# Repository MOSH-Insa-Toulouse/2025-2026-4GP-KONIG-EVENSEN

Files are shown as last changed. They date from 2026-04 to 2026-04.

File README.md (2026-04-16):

# LOWTECH FLEX SENSOR
## 2025-2026-4GP-KONIG-EVENSEN

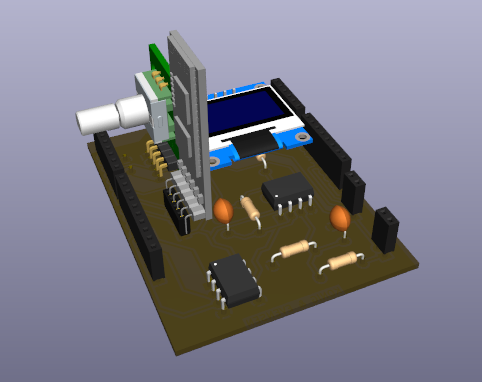
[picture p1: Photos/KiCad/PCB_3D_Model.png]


This work is regulated by the Creative Commons Licence CC BY 4.0, for more information 
[follow this link](https://creativecommons.org/licenses/by/4.0/).

---

## Introduction
In this project we sought to create a LowTech flex sensor based on the conduction properties of graphite. LowTech projects consist of developing technological solutions while respecting sobriety, efficiency, durability, maintainability, accessibility, autonomization, empowerment, connectedness and simplification. Hence, it promotes technology which is sustainable both environmentally and socially, as well as uncomplicated and accessible. The following sections will describe the different procedures of the development of the sensor, as well as an evaluation of the performance of the sensor. 

- [The Physics Behind the Graphite Sensor](#the-physics-behind-the-graphite-sensor)
- [Procedure](#procedure)
- [Amplifier Circuit Simulations](#amplifier-circuit-simulations)
- [Printed Circuit Board Design and Development](#printed-circuit-board-design-and-development)
- [Arduino Code](#arduino-code)
- [APK Application Design and Development](#apk-application-design-and-development)
- [Test Setup](#test-setup)
- [Datasheet](#datasheet)
- [Conclusion](#conclusion)

---

## The Physics Behind the Graphite Sensor
This project is based on the research of [Lin et al.](https://www.nature.com/articles/srep03812) on the use of "Pencil Drawn Strain Gauges and Chemiresistors on Paper". They showed that regular commercial pencils deposit fine graphite particles on paper during dry application due to friction. The graphite powder makes up a percolated network which works as a thin conductive film on the paper. This provides an incredibly simple deposition method for generating conductive films in various patterns.
By creating a specific U-shaped pencil trace (see [Datasheet](./GraphiteSensor_Datasheet/Datasheet_Graphite_Flex_Sensor.pdf)), the conductive properties of the graphite network can be used to measure compressive and tensile deflections, and we can therefore employ it as a strain gauge. When the graphite is in compression (inward deflection), the graphite particle network is compressed, creating a more closely connected conductive film, and hence lowering the resistance of the strain gauge. Conversely, tension (outward deflection) increases the resistance of the strain gauge as the distances between the graphite particles increase and disconnect the conduction pathways. The conduction between non-connected graphite particles remains possible due to the tunneling effect in granular systems.

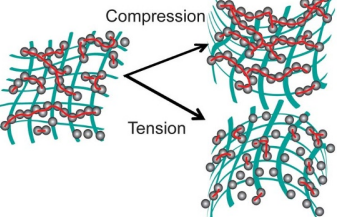
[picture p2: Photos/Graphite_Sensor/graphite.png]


The resistance of the pencil trace can easily be measured, and varies based on the type of pencil used (in this project HB, 3B and 6B). Softer pencils have higher graphite content and therefore show lower resistance.

The application of this principle allows for the production of low-cost, environmentally-friendly and uncomplicated paper-based electronics.

## Procedure
For this project we started off with the design of an amplification circuit based on an operational amplifier of the type LTC1050 for the amplification of the signal from the graphite sensor. Secondly, we designed and developed a printed circuit board for the implementation of the amplification circuit (employing a digital potentiometer of the type MCP41010), an OLED screen, a rotary encoder, a Bluetooth module of the type HC-05 and a commercial flex sensor. All datasheets for the commercial components can be found in the repository [Components_Datasheets](./Components_Datasheets/). The printed circuit board was designed as a shield for an Arduino UNO. Thereafter, we wrote an Arduino IDE script implementing all the components and facilitating the measurement and testing of the graphite flex sensor. Later we designed and developed an APK Application for Android using MIT App Inventor, which allows communication with the Arduino using the Bluetooth module. Finally, we developed a test setup for the quantitative analysis of the graphite sensor's development. All parts of the procedure are further developed in the following part.

## Amplifier Circuit Simulations
Before the conception of the circuit for the realization of the graphite sensor, we performed simulations of the amplifier circuit in order to predict its performance. For this simulation we used the program LTSpice, and the exact files used can be found in the repository [LTSpice_Files](./LTSpice_Files/). The amplifier circuit tested was as follows:

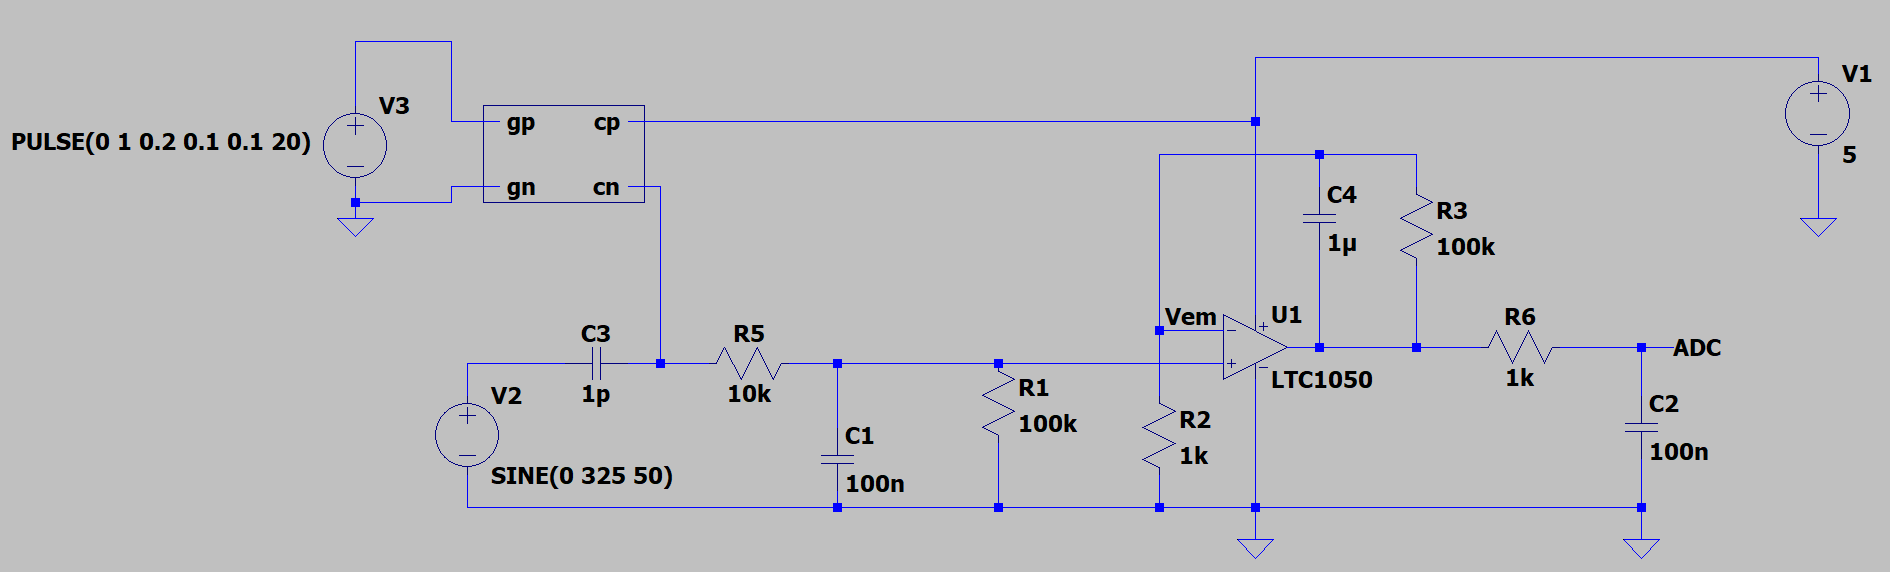
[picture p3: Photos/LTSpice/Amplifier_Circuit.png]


The graphite sensor is simulated by the following circuit:

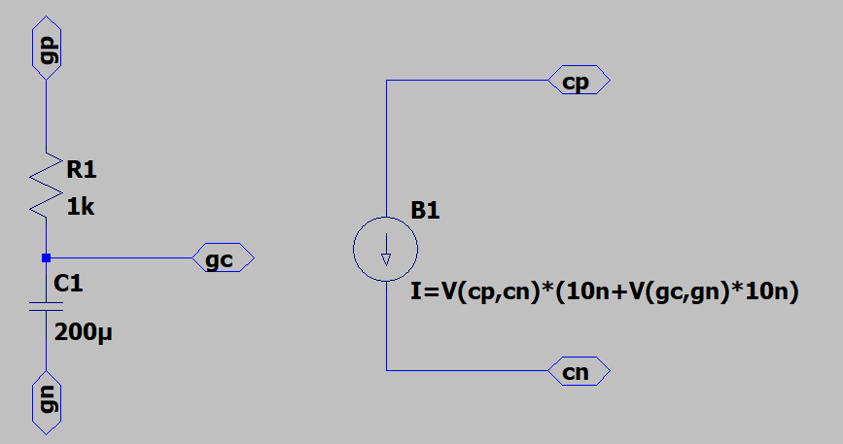
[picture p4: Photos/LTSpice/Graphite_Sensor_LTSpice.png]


As the graphite sensor constitutes a very sensitive system, it is extremely susceptible to noise at 50Hz coming from the capacitive coupling to the grid power at 230V, as shown by the Fourier transform of the acquired signal.

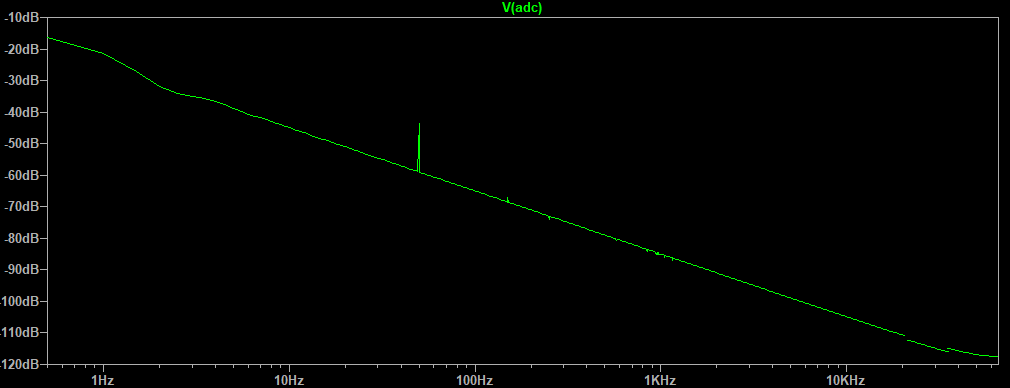
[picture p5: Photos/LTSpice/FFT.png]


The amplifier circuit serves as a low-pass filter with a cutoff frequency at approximately 1.6Hz to reduce the influence of this noise. It also serves to minimize the noise from the other components which will be added to the printed circuit board, such as the clock of the digital circuits and the radio frequency used for the Bluetooth communication. The circuit consists of a passive filter which minimizes high-frequency noise, an active filter of the type LTC1050, and a second passive filter for filtering out the noise coming from the processing of the signal.

During the testing of the circuit's transient response, the dependency on the capacitance C4 became evident. An increased value of the capacitance minimized the influence of noise on the signal, but increased the response time significantly. Contrarily, a decreased value enhanced the response time, but augmented the noise influence. A compromise between the two conflicting properties was made when determining the value of the capacitance.

C4 = 0.1 $\mu$ F
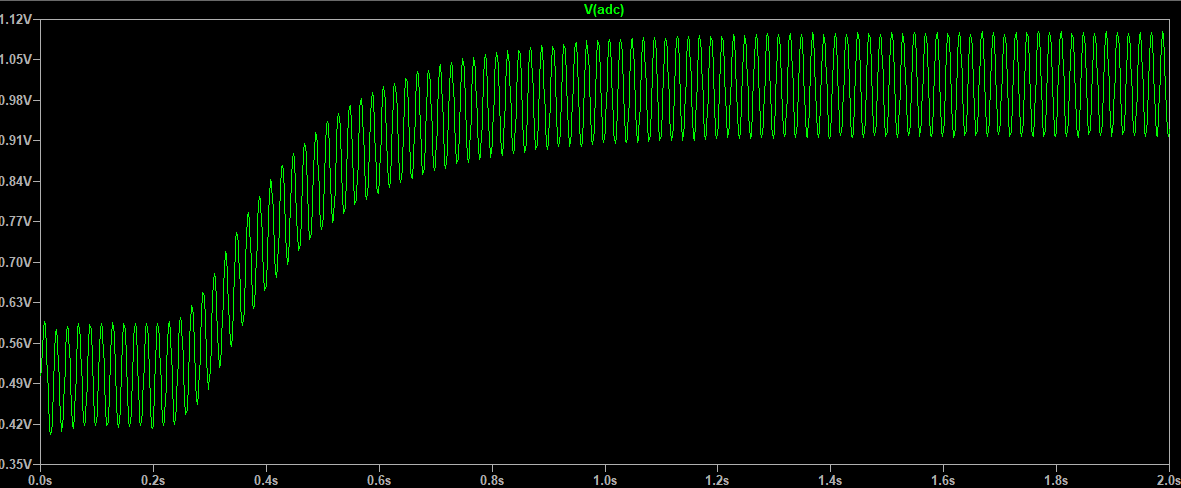
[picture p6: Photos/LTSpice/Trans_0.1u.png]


C4 = 1 $\mu$ F
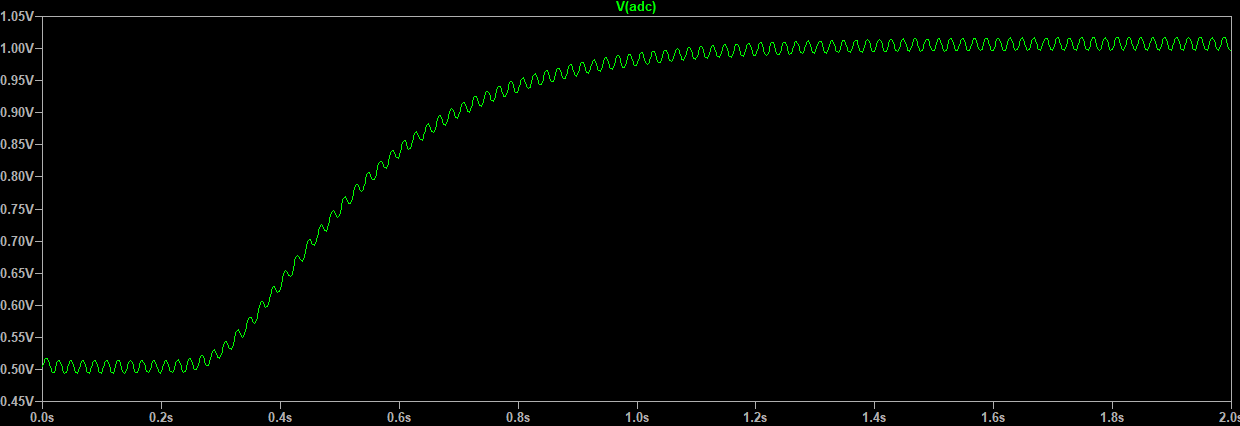
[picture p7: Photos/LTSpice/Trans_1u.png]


C4 = 10 $\mu$ F
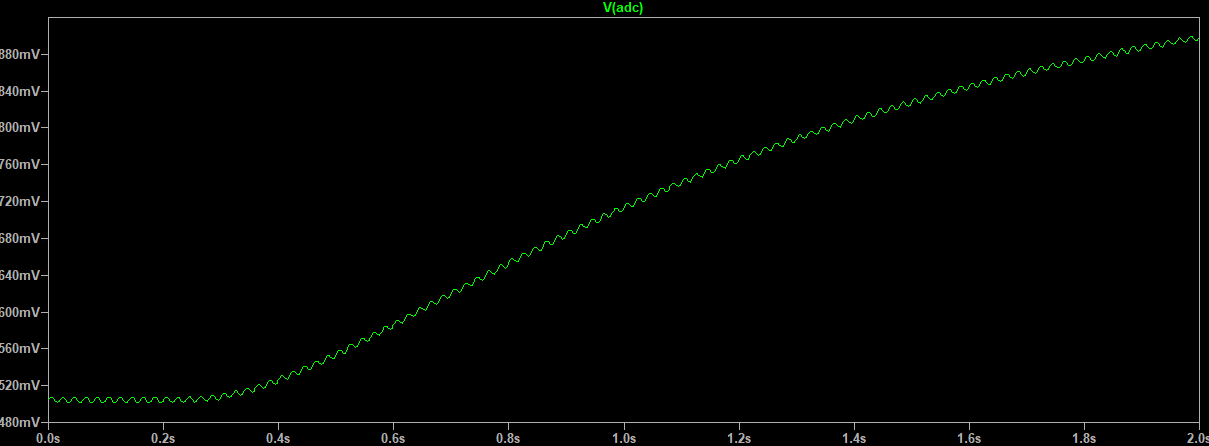
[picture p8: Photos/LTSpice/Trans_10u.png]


## Printed Circuit Board Design and Development
The design of the printed circuit board (PCB) destined for the use as a shield for an Arduino UNO was done using the program KiCad. Here, diagrams and footprints were made of all the necessary components, and the PCB was designed with the necessary connections between the components and the Arduino UNO. The files fro the diagram and the wiring of the PCB can be found in the repository [KiCad_Files](./KiCad_Files/). The PCB allows the connection between the Arduino UNO and the following components ([link to datasheets](./Components_Datasheets/)).

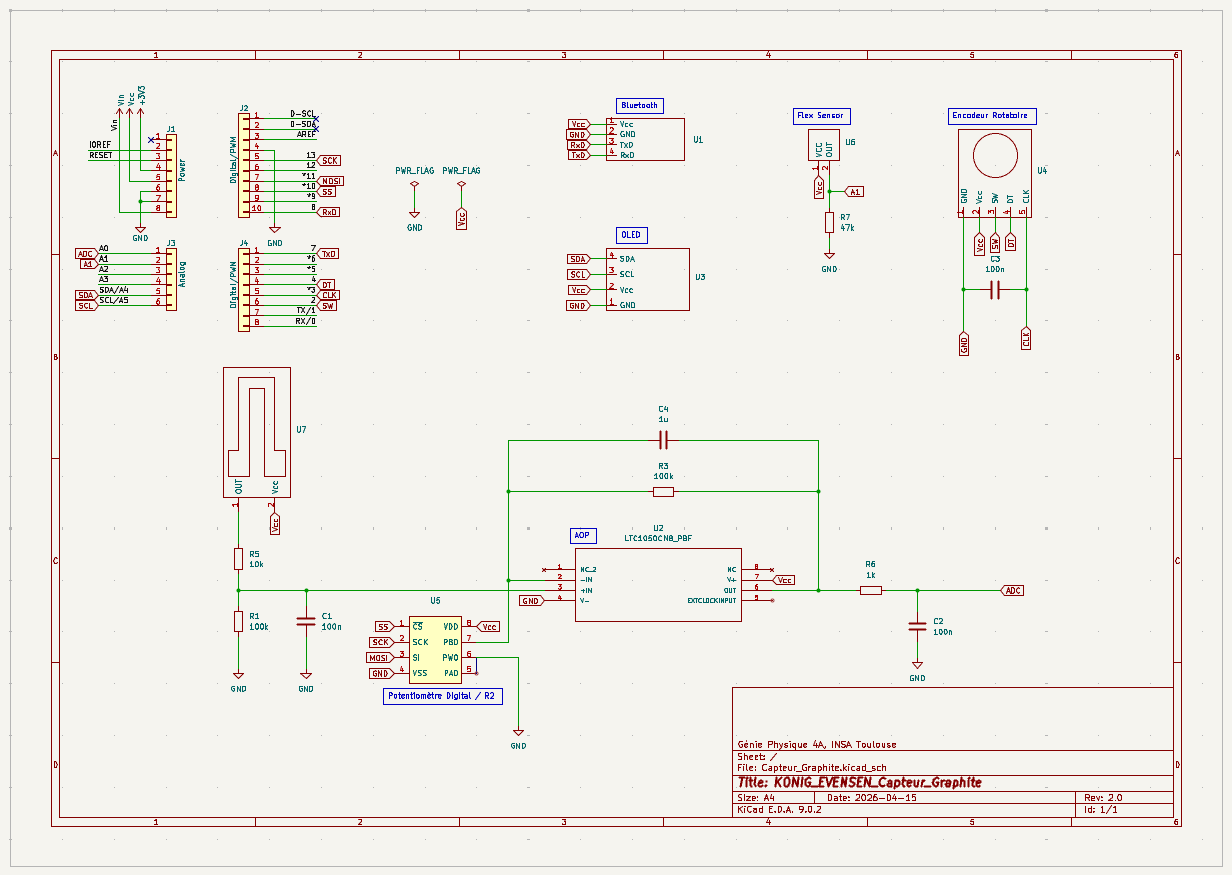
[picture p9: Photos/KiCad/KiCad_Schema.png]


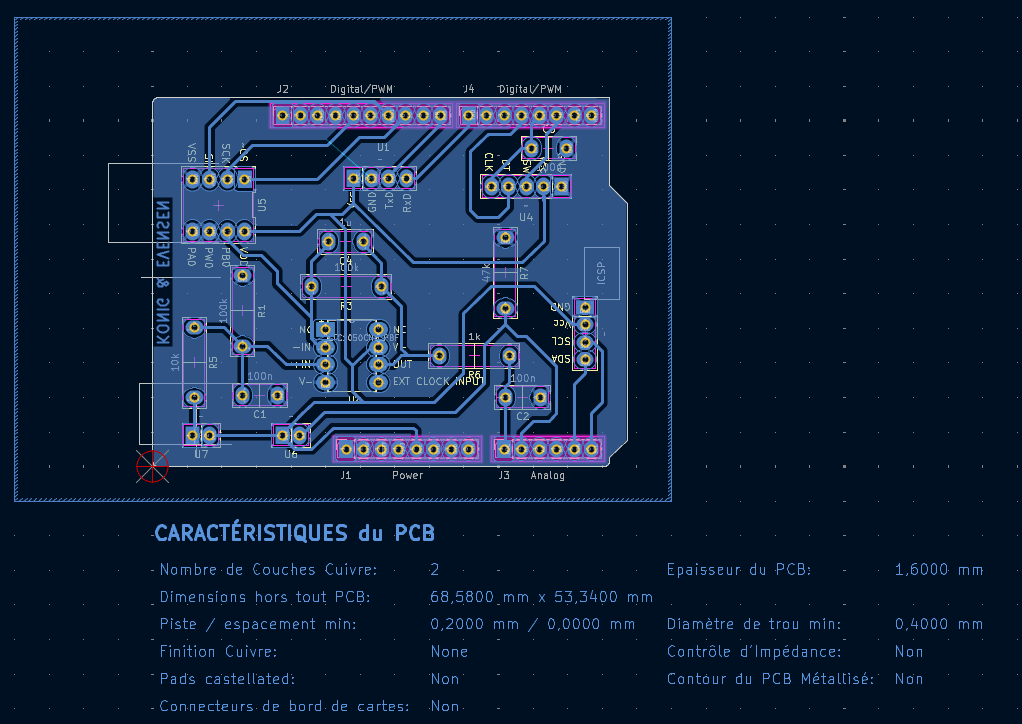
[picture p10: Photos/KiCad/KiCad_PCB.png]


### Graphite Sensor
The signal of the graphite sensor is connected to the Arduino UNO through the amplifier circuit based on the operational amplifier LTC1050. The digital potentiometer MCP41010 takes part of this circuit and is used to regulate the signal Vadc according to the following formula:

> $R_C = \frac{V_C}{V_A} \cdot R_1 \cdot \left(1 + \frac{R_3}{R_P}\right) - R_1 - R_5$

Where Rc is the resistance of the graphite sensor, Va is the voltage of the output of the amplifier circuit and Rp is the resistance of the digital potentiometer.

The voltage output from the amplifier circuit can be retrieved on the analog pin A0.

### Commercial Flex Sensor
The commercial flex sensor is connected using a resistance of 47kOhms in a voltage divider circuit. The resistance of the flex sensor can be retrieved on the analog pin A1.

### OLED Screen
The OLED Screen used is of the type SBC-OLED01 and uses the SCL (serial clock line) and SDA (serial data line) pins common for the I2C serial communication bus. I2C has a 7-bit address space and transfers data bit by bit between the controller and the target. The SDA and SCL pins correspond to the pin A4 and A5, respectively, on the Arduino UNO.

### Rotary Encoder
A rotary encoder of the type KY-040 is connected using the CLK, DT and SW pins. The SW (switch) and CLK (clock) are connected to respectively the pins D2 and D3 of the Arduino UNO as these permit the use of interruptions, as is generated on CLK when rotating the rotary encoder. The DT (data) pin connects to D4.
Inside the rotary encoder, two switches serve to determine a rotation as they are either both opened or closed in each encoder position. The order in which the switches change state is used to determine the direction of the rotation, as shown by the diagram below:

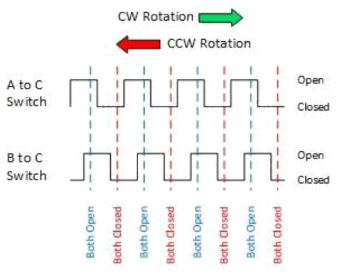
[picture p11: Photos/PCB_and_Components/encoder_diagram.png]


A capacitor is connected between the ground and the CLK pin in order to stabilize the interrupt signal.

### Bluetooth Module
Bluetooth permits wireless communication between devices, and in this project a Bluetooth module of the type HC-05 is used to establish communication between the Arduino UNO and other devices. It communicates using radio frequencies around 2.4GHz, which is the same as mobile phones and Wi-Fi. This module provides serial communication over the TxD (transmission) and RxD (receiving) pins, connected to the TxD (7) and RxD pins (8) of the Arduino UNO. 

### Printed Circuit Board Development
For the development of the PCB a PDF-file of the PCB design was printed on transparent paper and used as a mask during UV-exposure of a laminate board covered by a thin layer of copper and photo resist. The exposed photo resist is removed using an alkaline solution, and a copper solvent solution bath removes the uncovered copper. Lastly, the hardened photo resist is removed and only the wanted copper traces on the laminate board are left.

Afterwards, holes are drilled and passive components, as well as supports for the active components, are welded to the printed circuit board.

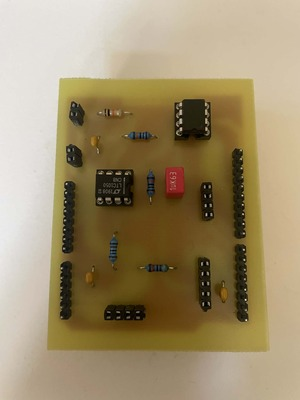
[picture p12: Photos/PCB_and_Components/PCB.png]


## Arduino Code
After the conception of the PCB, we continued to the development of an Arduino IDE code allowing control of the components. The Arduino code has multiple functionalities interconnecting the electrical components.

The use of the rotary encoder controls a menu on the OLED screen. The menu includes three different modes: "Flex", "Graphite" and "GitHub QR". Clicking the rotary encoder accesses the different modes, and clicking it again returns to the main menu.

**Flex:** 
The Flex mode permits the monitoring of the commercial flex sensor, printing the resistance and the corresponding angle to the serial monitor of Arduino IDE.

**Graphite:**
The Graphite mode permits the monitoring of the LowTech graphite sensor. The first time the graphite mode is activated, a calibration of the digital potentiometer is started, changing its resistance value in order to get a Vadc corresponding to approximately 2.5V (512 bits). When adjusted, the graphite mode prints the resistance of the graphite sensor to the serial monitor of Arduino IDE.

**GitHub QR:**
The GitHub QR mode displays a QR code which links to the GitHub page of this project.

The Arduino code also manages the serial communication over Bluetooth which is used for the transfer of data between the Arduino UNO and an Android device when using the APK Application which will be described in the following section. The full code can be found in the repository [Arduino_Code](./Arduino_Code/).

## APK Application Design and Development
An APK Application for Android has been developed using the program MIT App Inventor. This application can easily be downloaded to any Android device and permits a simple monitoring of the Arduino UNO. The application allows for connecting to a Bluetooth module such as the HC-05. Depending on if the Flex mode or the Graphite mode is activated, the graphs in the application display the current measured resistance and the relative resistance when "Start" is clicked. When "Stop" is clicked the measurement will stop, and if "Start" is then reclicked, the graphs reset and a new measurement starts. The results of a measurement can be shared or saved using the "Share Result" button. It will then be shared as a text file with the format "x1,y1;x2,y2;...". A "Scan QR Code" button permits the scanning of QR codes, such as the one displayed in QR mode, leading directly to the GitHub page of this project. The programming of the application is shown by the blocs in the repository [APK_Application](./APK_Application/).

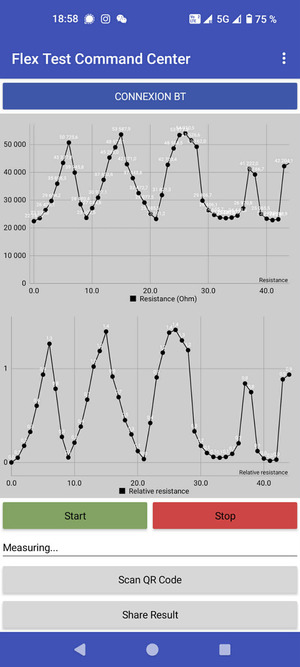
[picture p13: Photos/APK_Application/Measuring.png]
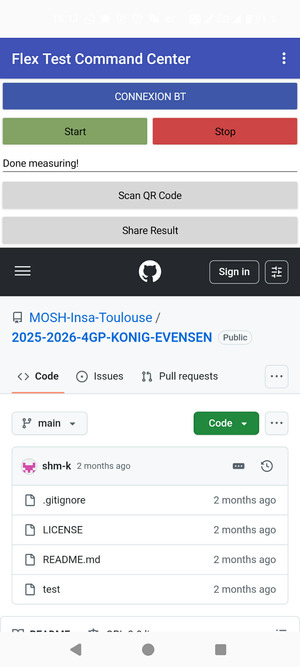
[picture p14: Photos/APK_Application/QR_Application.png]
 

## Test Setup
For the testing of the performance of the LowTech graphite sensor, we developed a simple test setup based on the principle of a three-point flexural test. We designed a 3D model using TinkerCad and printed it with the help of extremely knowledgeable and helpful representatives of the INSA Toulouse FabLab Fabric'INSA. The STL-files can be found in the repository [TestSetup_Files](./TestSetup_Files/Projet_MOSH.stl).

The test setup enables both tension and compression tests, and can be used for both the commercial flex sensor and the LowTech graphite sensor at the same time. The absolute value of the strain is calculated using the following formula:

> $\epsilon = \frac{6Dd}{L^2}$

where D(mm) is the maximum deflection of the middle of the graphite sensor, d(mm) is the thickness of the paper, and L(mm) is the length between the two supports of the test module.

## Datasheet
Lastly, we created a [datasheet](./GraphiteSensor_Datasheet/Datasheet_Graphite_Flex_Sensor.pdf) for the LowTech graphite flex sensor, of the type Extra Long Special Edition C5462310 (the number corresponding to the CID PubChem Compound Identification of graphite) in a manner corresponding to the commercial flex sensor. Specifications of the properties and performance of the graphite sensor are listed in order to increase the usability of the sensor.

## Conclusion
In order to conclude on the results of this project, we have analyzed the performance of the LowTech graphite sensor compared to a commercial flex sensor. We identified sensitivity as a relevant metric as this determines the smallest measurable difference in strain, the input value. When analyzing the sensitivity of the graphite sensor, we found that the harder pencils showed a higher sensibility (see the [datasheet](./GraphiteSensor_Datasheet/Datasheet_Graphite_Flex_Sensor.pdf) of the graphite sensor). However, when testing the sensitivity of the commercial flex sensor in extension (as it can only be bent in one direction), the sensitivity of the LowTech graphite sensor proved much weaker.

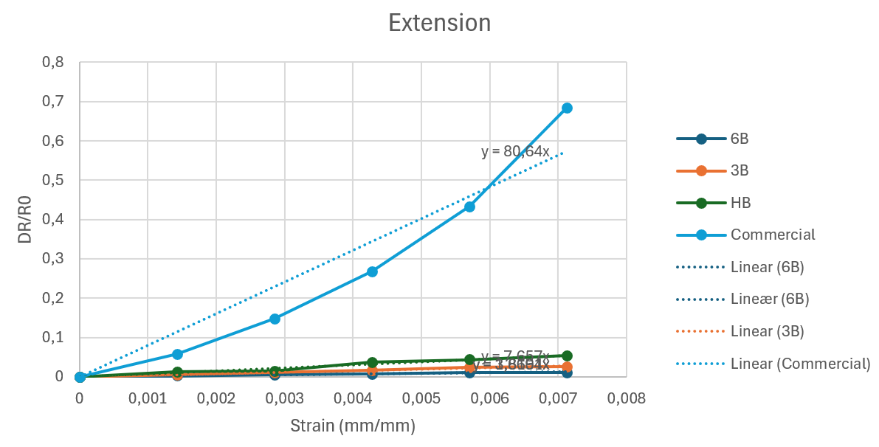
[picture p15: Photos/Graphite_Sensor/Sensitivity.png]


In addition, the reproducibility of the graphite sensor is questionable. The results from the tests show little to no predictability of the results with extreme uncertainty in the resistance response to the application of both tension and compression to the graphite sensor. We estimate that this is partly because of multiple sources of error coming from the hardware and the fabrication of the PCB. With higher accuracy in the fabrication process, a more predictable and reproducible performance might be possible.

Nonetheless, the feasibility and the LowTech aspect of the graphite sensor must be appreciated. This project shows that a well-functioning flex sensor can be fabricated from the simplest materials, particularly a pencil and paper, and with little to no previous experience with the fabrication of integrated circuits. Moreover, easily accessible components and simple processes serve to increase the performance of the graphite sensor noticeably. Even though the weak sensitivity decreases the probability of the graphite sensor becoming industrializable, the graphite sensor represents a technology available for almost everyone. All in all, this project shows that a transition to LowTech solutions makes technology much more accessible and increases its sustainability for both people and the planet.

---

Created by Svea KÖNIG and Maia EVENSEN (4GP INSA Toulouse)

For support, contact konig@insa-toulouse.fr or evensen@insa-toulouse.fr

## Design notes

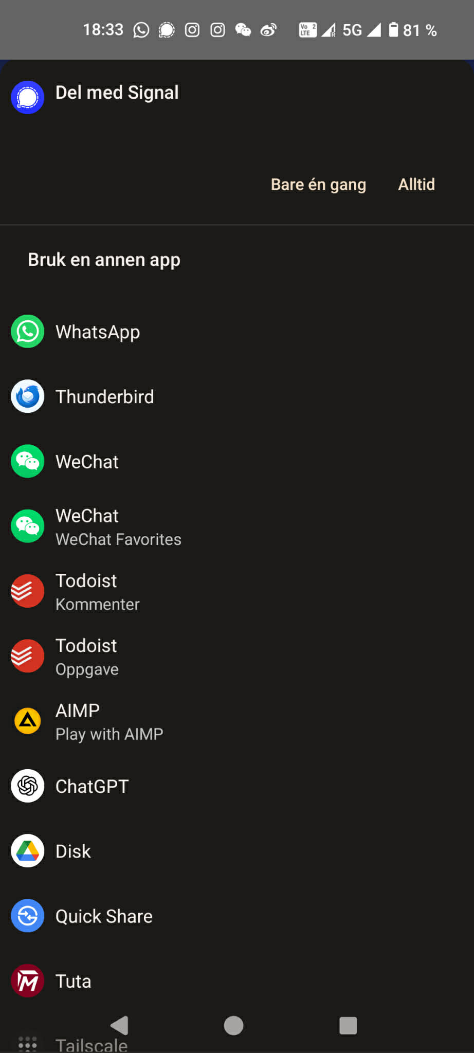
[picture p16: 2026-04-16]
Photos/APK_Application/Share.png

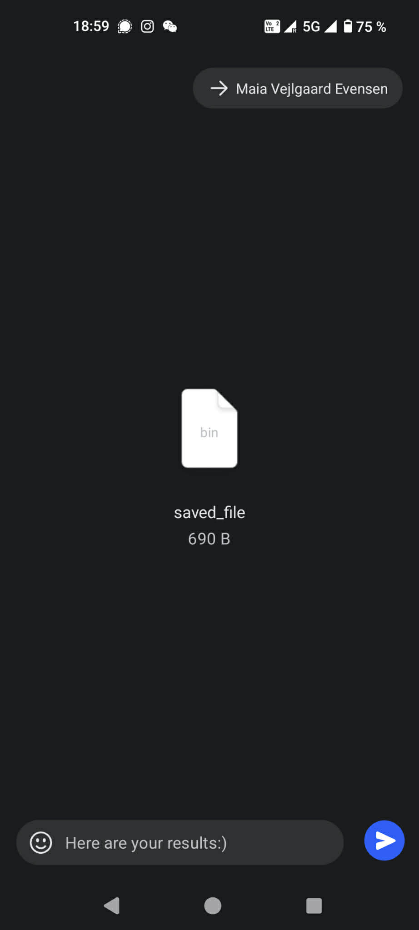
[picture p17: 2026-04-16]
Photos/APK_Application/Share_File.png

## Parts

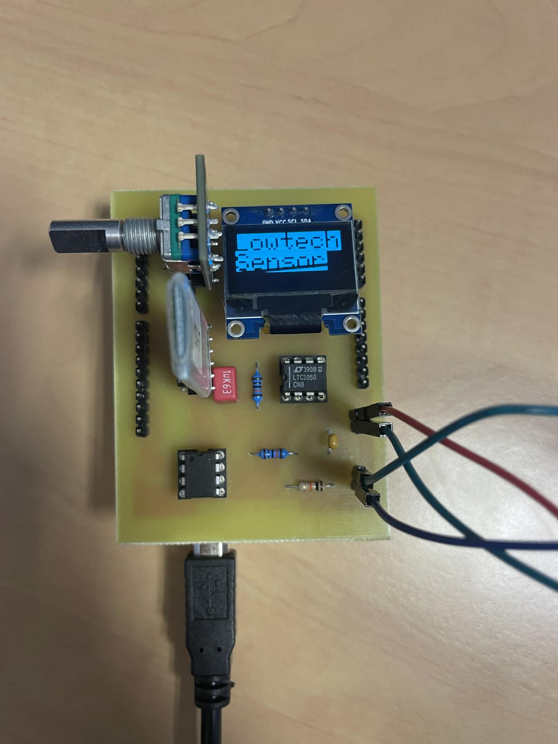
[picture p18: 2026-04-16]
Photos/PCB_and_Components/LowTech_Mode.png

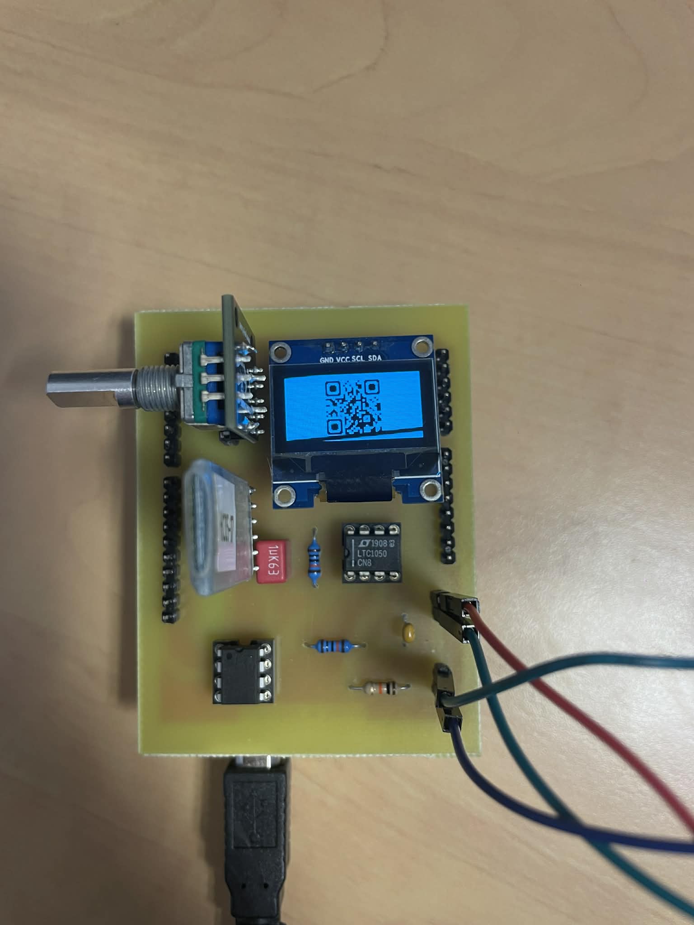
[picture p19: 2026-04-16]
Photos/PCB_and_Components/QR_OLED.png

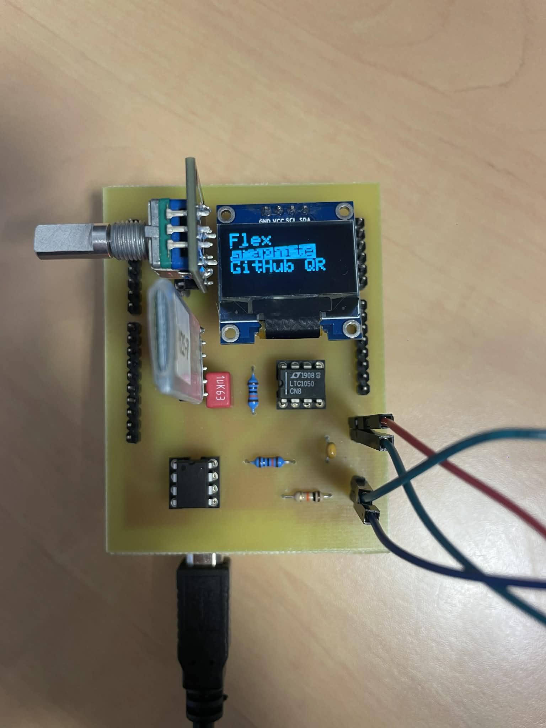
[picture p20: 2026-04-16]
Photos/PCB_and_Components/Main_Menu.png

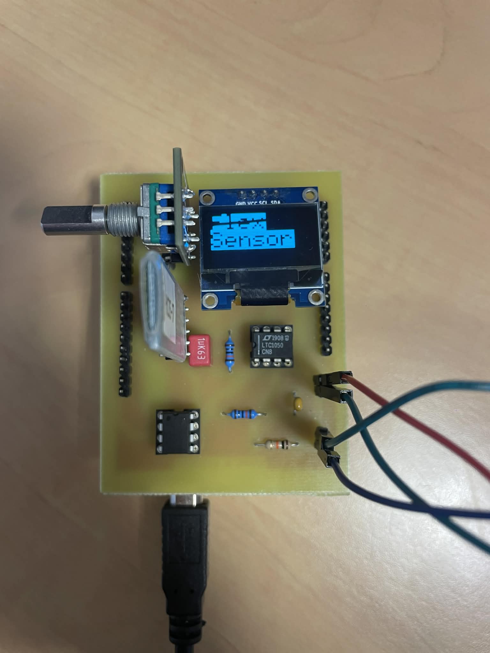
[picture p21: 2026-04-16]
Photos/PCB_and_Components/Flex_Mode.png

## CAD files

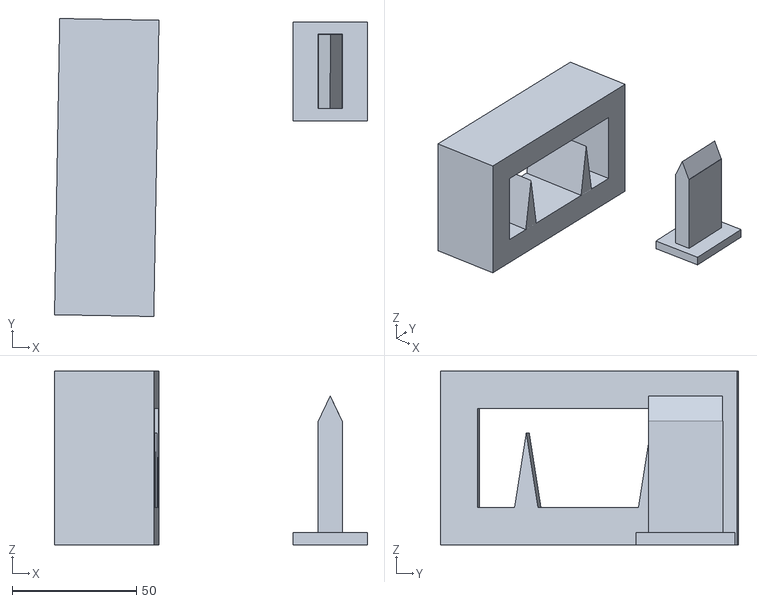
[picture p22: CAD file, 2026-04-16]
TestSetup_Files/Projet_MOSH.stl
126.0 x 120.0 x 70.0

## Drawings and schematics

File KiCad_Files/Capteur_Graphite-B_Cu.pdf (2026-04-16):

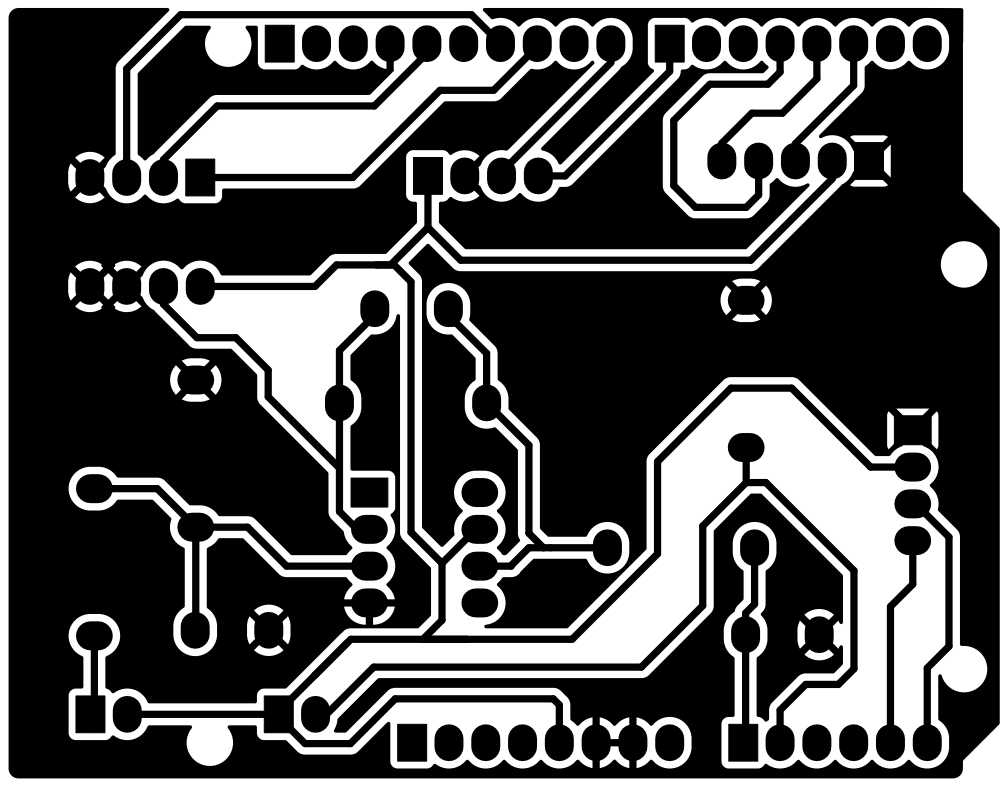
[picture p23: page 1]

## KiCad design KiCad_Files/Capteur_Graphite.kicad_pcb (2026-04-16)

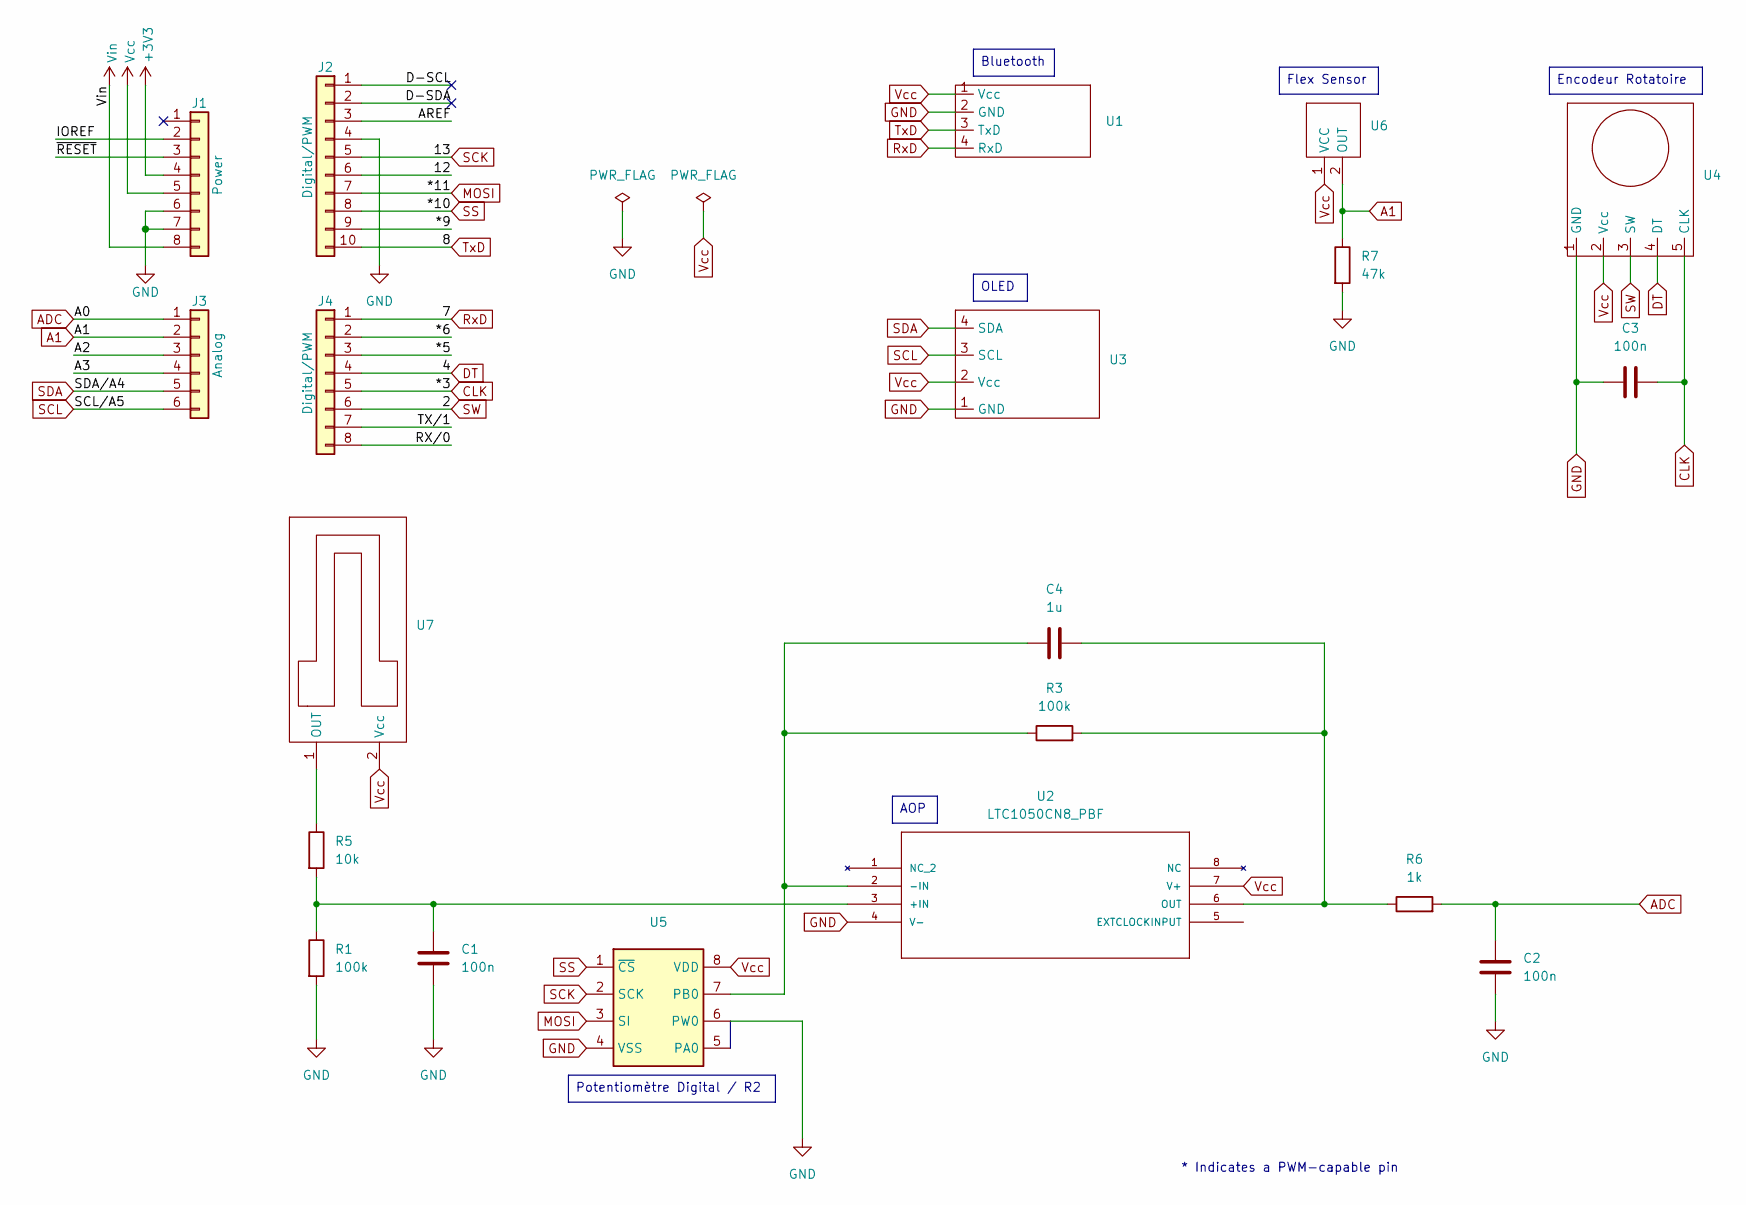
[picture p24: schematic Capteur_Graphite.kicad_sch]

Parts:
C1, C2, C3: 100n; Capacite
C4: 1u; Capacite
J1: Power; PinSocket_1x08_P2.54mm_Vertical
J2: Digital/PWM; PinSocket_1x10_P2.54mm_Vertical
J3: Analog; PinSocket_1x06_P2.54mm_Vertical
J4: Digital/PWM; PinSocket_1x08_P2.54mm_Vertical
R1, R3: 100k; Resistance
R5: 10k; Resistance
R6: 1k; Resistance
R7: 47k; Resistance
U1: BLUETOOTH_HC05
U2: LTC1050CN8_PBF; LTC1050
U3: OLED
U4: Encodeur_Rotatoire
U5: MCP41010
U6: Flex_Sensor
U7: Graphite_Flex_Sensor

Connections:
+3V3: J1.4
/12: J2.6
/*5: J4.3
/*6: J4.2
/*9: J2.9
/A2: J3.3
/A3: J3.4
/AREF: J2.3
/D-SCL: J2.1
/D-SDA: J2.2
/IOREF: J1.2
/RX/0: J4.8
/TX/1: J4.7
/~RESET: J1.3
A1: J3.2, R7.1, U6.2 (OUT)
ADC: C2.1, J3.1, R6.2
CLK: C3.2, J4.5, U4.5 (CLK)
DT: J4.4, U4.4 (DT)
GND: C1.2, C2.2, C3.1, J1.6, J1.7, J2.4, R1.2, R7.2, U1.2 (GND), U2.4 (V-), U3.1 (GND), U4.1 (GND), U5.4 (VSS), U5.5 (PA0), U5.6 (PW0)
MOSI: J2.7, U5.3 (SI)
unnamed: C1.1, R1.1, R5.2, U2.3 (+IN)
unnamed: C4.1, R3.1, U2.2 (-IN), U5.7 (PB0)
unnamed: C4.2, R3.2, R6.1, U2.6 (OUT)
unnamed: R5.1, U7.1 (OUT)
RxD: J4.1, U1.4 (RxD)
SCK: J2.5, U5.2 (SCK)
SCL: J3.6, U3.3 (SCL)
SDA: J3.5, U3.4 (SDA)
SS: J2.8, U5.1 (~CS)
SW: J4.6, U4.3 (SW)
TxD: J2.10, U1.3 (TxD)
Vcc: J1.5, U1.1 (Vcc), U2.7 (V+), U3.2 (Vcc), U4.2 (Vcc), U5.8 (VDD), U6.1 (VCC), U7.2 (Vcc)
Vin: J1.8

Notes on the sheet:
* Indicates a PWM-capable pin
Flex Sensor
OLED
Potentiomètre Digital / R2
AOP
Bluetooth
Encodeur Rotatoire

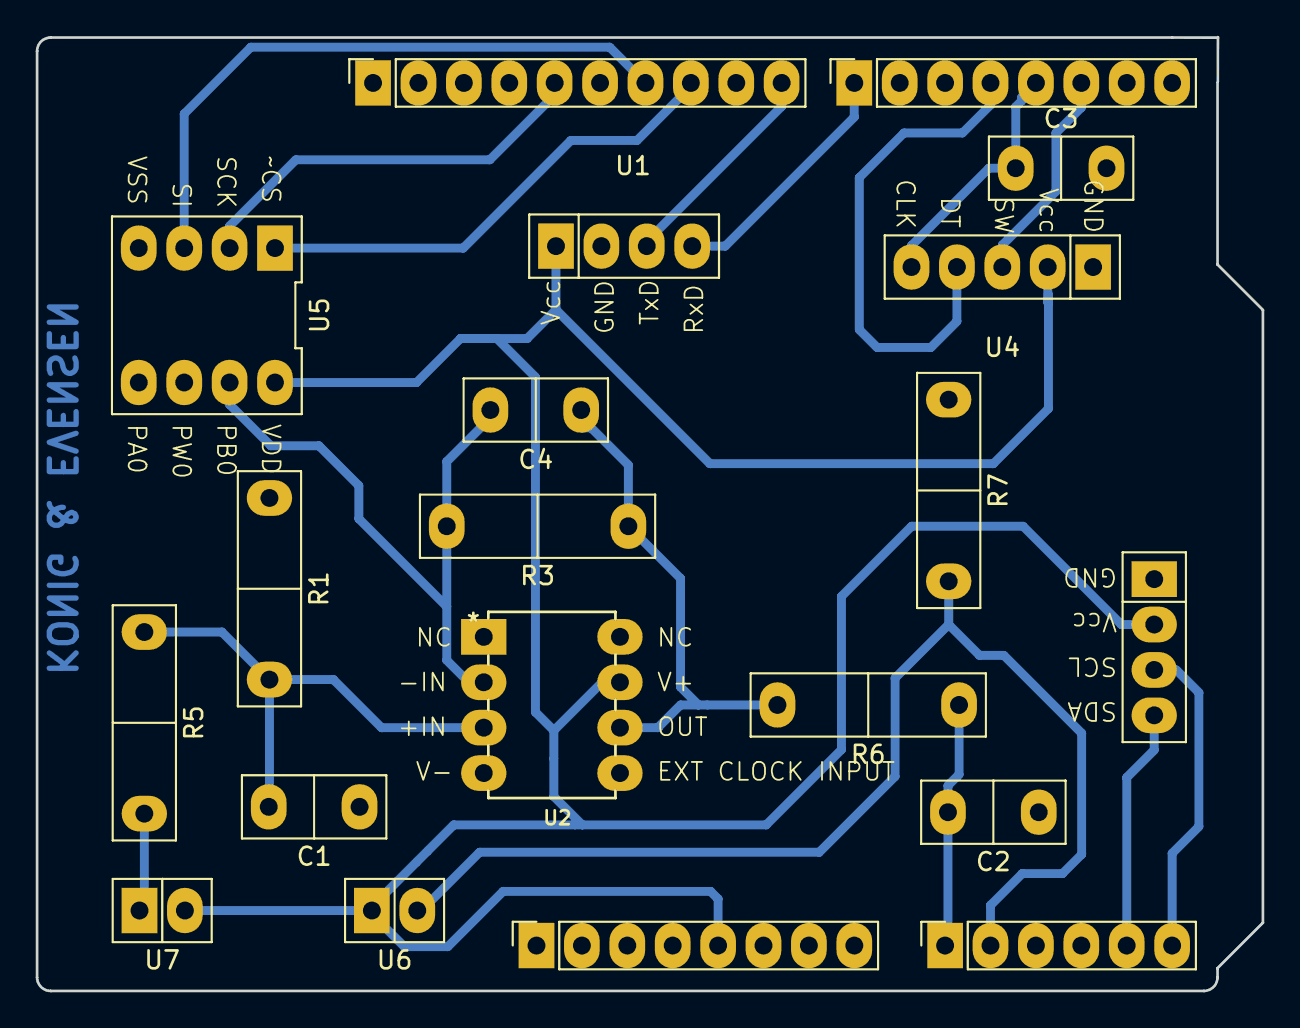
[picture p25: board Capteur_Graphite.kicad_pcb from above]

Board: 2 copper layers, 68.6 x 53.4 mm, 20 parts (0 on the bottom side), 18 nets.

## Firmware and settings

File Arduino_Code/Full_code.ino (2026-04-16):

/*
Program for the handling of a rotary encoder, an OLED screen, Bluetooth communication 
with an android application made with MIT App Inventor via a HC-05 bluetooth module, a
commercial flex sensor and an amplifier circuit using a digital potentiometer to determine
the resistance of a LowTech graphite strain sensor.
The program is based on three different modes:
"Flex Sensor mode":
- Measures the resistance of the commercial flex sensor and transfers it to the android application
  where it is plotted to a graph for resistance and relative resistance.
"LowTech Sensor mode":
- Measures the resistance of the LowTech graphite sensor and transfers it to the android application
  where it is plotted to a graph for resistance and relative resistance.
"GitHub QR":
- Displays a QR code from the homemade arduino library QR.h which leads directly to the GitHub page
  of this project, and can be scanned using the android application.


Full description of the wiring of the components needed for this program:
  /////////////////////////////////////////
   Arduino Uno Rotary Encoder connections:
   Uno            KY-040
   ------------------------
   GND           GND (pin 1)
   5V            +   (pin 2)
   D02           SW  (pin 3)
   D03           CLK (pin 5 (A))
   D04           DT  (pin 4 (B))
  /////////////////////////////////////////
   Arduino Uno OLED screen (I2C) connections:
   Uno           SBC-OLED01
   ------------------------
   GND           GND (pin 1)
   5V            VCC (pin 2)
   A04           SDA (pin 4)
   A05           SCL (pin 3)
  /////////////////////////////////////////
   Arduino Uno Serial Bluetooth connections:
   Uno            HC-05
   ------------------------
   5V            VCC (pin 1)
   GND           GND (pin 2)
   D07 (TxD)     RxD (pin 4)
   D08 (RxD)     TxD (pin 3)
  /////////////////////////////////////////
   Arduino Uno Flex Sensor connections:
   Uno         SpectraSymbol FS
   ------------------------
   5V            Vcc (pin 1)
   A01           Output (pin 2)
  /////////////////////////////////////////
   Arduino Uno SPI connections:
   Uno            MCP41100
   ------------------------
   D10 (SS)      CS  (pin 1)
   D11 (MOSI)    SI  (pin 3)
   D13 (SCK)     SCK (pin 2)
   GND           VSS (pin 4)
   GND           PA0 (pin 5)
   GND           PWD (pin 6)
   (AOP pin 6)   PB0 (pin 7)
   5V            VDD (pin 8)
  /////////////////////////////////////////
   Arduino Uno Amplifier Circuit connections:
   Uno            LTC1050
   ------------------------
   A00           VADC
   5V            Vcc (Graphite sensor pin 1)
   GND           V- (pin 4)
   5V            V+ (pin 7)
   See KiCad_Schema.png for more information
   about the circuit wiring.
  /////////////////////////////////////////
*/


// Inclusion of libraries needed for the program
#include <SPI.h> // Library used for SPI bus, communication with the digital potentiometer
#include <Adafruit_SSD1306.h> // Library used for the initialization of the OLED screen
#include <QR.h> // Library used for the implementation of a QR code leading directly to the GitHub for this project MOSH-Insa-Toulouse/2025-2026-4GP-KONIG-EVENSEN
#include <SoftwareSerial.h> // Library used for the Bluetooth serial communication between an android application created with the program MIT App Inventor and a HC-05 Bluetooth module


// Variables for the rotary encoder
#define Switch        2       // Switch connection
#define encoder0PinA  3       // CLK Output A needs to be at pin 2 or 3 as we are using interrupts
#define encoder0PinB  4       // DT Output B
int lastButton = HIGH;        // Variable for the last state of the rotary encoder button in order to handle clicks
volatile int encoder0Pos = 1; // Variable for the position of the rotary encoder in the menu list
volatile int touched = 0;     // Variable for determining if the rotary encoder has been clicked


// Variables for the OLED screen
#define OLED_width      128         // Width of OLED screen in pixels
#define OLED_height     64          // Height of OLED screen in pixels
#define OLED_pinReset   -1          // Reset of OLED shared with the Arduino
#define OLED_I2Caddress 0x3C        // Address of OLED screen on I2C bus corresponding to 0x78 at the back of the OLED screen
Adafruit_SSD1306 OLED_screen(OLED_width, OLED_height, &Wire, OLED_pinReset); // Initialization of the OLED screen


// Variables for the Bluetooth serial communication
byte serialRX;          // Variable for the bytes received from the application
volatile byte RX = 0;   // Variable for the state of RX
int start = 0;          // Variable for determining if a measure should be done
SoftwareSerial switchSerial (8,7); // Initialization of the serial communication of the bluetooth, sets the pin 7 as TxD and 8 as RxD on the Arduino UNO


// Variables for the commercial flex sensor
const int flexPin = A1;                 // Pin connected to voltage divider output
const float Vcc = 5;                    // Voltage at Ardunio 5V line
const float R_DIV = 47000.0;            // Resistor used to create a voltage divider 47kOhm
const float flatResistance = 22000.0;   // Resistance when flat
const float bendResistance =  63000.0;  // Resistance at 90 deg


// Variables for the potentiometer
const byte csPin                    = 10;      // MCP42100 chip select pin
const int  maxPositions             = 256;     // The digital potentiometer wiper can move from 0 to 255 = 256 positions
const long rAB                      = 92500;   // 100k pot resistance between terminals A and B
const byte rWiper                   = 125;     // 125 ohms pot wiper resistance
const byte pot0                     = 0x11;    // pot0 addr // B 0001 0001
const byte pot0Shutdown             = 0x21;    // pot0 shutdown // B 0010 0001
volatile int potentiometerWiperPos  = 20;      // Initial wiper position of the digital potentiometer corresponding to 7351 Ohms
long       resistanceWB             = ((rAB * potentiometerWiperPos) / maxPositions ) + rWiper;   // Works as R2 in the amplifier circuit
volatile int calibrated             = 0;       // Variable for determining if the potentiometer has been calibrated


// Variables for the amplification circuit of the graphite sensor
const int graphitePin = A0;           // The signal Vadc is received on the pin A0 of the Arduino
const int VccBits = 1024;             // The Vcc voltage of 5V given in bits
const float r1 = 100.0*(pow(10,3));   // The resistance value of R1 100kOhm
const float r3 = 100.0*(pow(10,3));   // The resistance value of R3 100kOhm
const float r5 = 10.0*(pow(10,3));    // The resistance value of R5 10kOhm


// Setup needed for declaring pinmodes and establishing communication routes
void setup() {
  // Initialization of serial monitor, baudrate 9600
  Serial.begin(9600);

  // Rotary encoder
  pinMode(encoder0PinA, INPUT);           // Set CLK pin to input
  digitalWrite(encoder0PinA, HIGH);       // Turn on pullup resistor
  pinMode(encoder0PinB, INPUT);           // Set DT pin to input
  digitalWrite(encoder0PinB, HIGH);       // Turn on pullup resistor
  attachInterrupt(1, encoder_interrupt, RISING);  // Encoder pin on interrupt 1 --> pin D03 of the Arduino UNO

  // OLED
  if(!OLED_screen.begin(SSD1306_SWITCHCAPVCC, OLED_I2Caddress)) // Initialization of OLED screen
    while(1); // Stops the program by creating an infinite loop if the OLED initialization fails

  // Bluetooth module
  pinMode(8, INPUT);        // Declares RxD as input on the arduino
  pinMode(7, OUTPUT);       // Declares TxD as output on the arduino
  switchSerial.begin(9600); // Initialization of switchSerial used for communication over Bluetooth, baudrate 9600
  switchSerial.flush();     // Flushes any data left on the communication bus

  // Flex Sensor
  pinMode(flexPin, INPUT); // Set flexPin in input mode

  // Potentiometer
  digitalWrite(csPin, HIGH);   // Chip select default to de-selected
  pinMode(csPin, OUTPUT);      // Configure chip select as output
  SPI.begin();                 // Initialization of SPI bus for communication with the digital potentiometer

  // Graphite Sensor
  pinMode(graphitePin, INPUT); // Set graphitePin in input mode
}


// Loop function runs continuously when the program is uploaded to the Arduino UNO
void loop() {
  // Prints the position of the rotary encoder from the menu
  Serial.print("Position:");
  Serial.println (encoder0Pos, DEC);
  
  // Reads the rotary encoder button to check if it has been clicked
  read_encoder_button();
  
  // Updates the OLED screen
  screen_OLED();

  // Creates a switchSerialEvent every time a message is sent from the application over Bluetooth
  if (switchSerial.available() > 0){
    switchSerialEvent();
  }

  // When a switchSerialEvent is triggered, this function runs, starting and stopping the measurement
  bluetooth_data_handling();
  
  // This function, sending the resistance value of the flex sensor (1) or the graphite sensor (2), runs between the instants where "Start" and "Stop" are clicked
  if (start){
    if (touched == 1 && encoder0Pos == 1) {
      flex_getResistance();
    } 
    if (touched == 1 && encoder0Pos == 2) {
      graphite_getResistance();
    } 
  }

  // Delay between loops to increase the stability of the program
  delay(500);
}


/////////////////////////////////////////// ROTARY ENCODER FUNCTIONS ////////////////////////////////////////////////
// Function managing a rotary encoder button click
void read_encoder_button(){
  int currentButton = digitalRead(Switch); // Reads the current state of SW, 0 when held in, 1 when at rest
  if (lastButton == HIGH && currentButton == LOW){ // Triggered when the current state of SW is 0 and the last was 1
    touched = !touched; // Changes the value of touched, 1 when entering a menu choice, 0 when at main menu
    delay(50); // Simple debounce for stability
  }
  lastButton = currentButton; // Updates the last button state
}


// Function for handling interrupts when the rotary encoder is rotated
void encoder_interrupt() {
  // This case corresponds to a clockwise rotation of the rotary encoder and increases the encoder0Pos up to 3 until it resets at 1
  if (digitalRead(encoder0PinA)==HIGH && digitalRead(encoder0PinB)==LOW) {
    if (encoder0Pos < 3){
      encoder0Pos++;
    } else encoder0Pos = 1;
  // This case corresponds to a anti-clockwise rotation of the rotary encoder and decreases the encoder0Pos down to 1 until it resets at 3
  } else if (digitalRead(encoder0PinA)==HIGH && digitalRead(encoder0PinB)==HIGH) {
    if (encoder0Pos > 1){
      encoder0Pos--;
    } else encoder0Pos = 3;
  }
}


/////////////////////////////////////////// OLED SCREEN FUNCTIONS ///////////////////////////////////////////////////
void screen_OLED() {
  // If touched is 0, the main menu is displayed
  if (touched == 0) {
    OLED_screen.clearDisplay();               // Clears the display
    OLED_screen.setTextSize(2);               // Sets the size of the characters
    OLED_screen.setCursor(0, 0);              // Initializes the cursor at (0,0)
    OLED_screen.setTextColor(SSD1306_WHITE);  // Sets the text color to white
    // Prints the menu choices in order: "Flex", "Graphite" and "GitHub QR"
    OLED_screen.println("Flex");
    OLED_screen.println("Graphite");
    OLED_screen.println("GitHub QR");
    // Changes the color of the background to white and the text to black for the current menu choice
    if(encoder0Pos == 1) { // encoder0Pos == 1 corresponds to the "Flex" choice
      OLED_screen.setCursor(0, 0); // Sets the cursor at (0,0) which corresponds to the first line
      OLED_screen.setTextColor(SSD1306_BLACK, SSD1306_WHITE); // Text color black and background color white
      OLED_screen.println("Flex"); // Reprints the "Flex" choice with new colors
    }
    else if(encoder0Pos == 2) { // encoder0Pos == 2 corresponds to the "Graphite" choice
      OLED_screen.setCursor(0, 15); // Sets the cursor at (0,15) which corresponds to the second line
      OLED_screen.setTextColor(SSD1306_BLACK, SSD1306_WHITE); // Text color black and background color white
      OLED_screen.println("Graphite"); // Reprints the "Graphite" choice with new colors
    }
    else if(encoder0Pos == 3) { // encoder0Pos == 3 corresponds to the "GitHub QR" choice
      OLED_screen.setCursor(0, 30); // Sets the cursor at (0,30) which corresponds to the third line
      OLED_screen.setTextColor(SSD1306_BLACK, SSD1306_WHITE); // Text color black and background color white
      OLED_screen.println("GitHub QR"); // Reprints the "GitHub QR" choice with new colors
      }
    }
  // If touched is 1, a choice of mode has been made by clicking the rotatry encoder button, and the corresponding mode is displayed
  else {
    if(encoder0Pos == 1) { // encoder0Pos == 1 corresponds to the "Flex sensor" mode
      OLED_screen.clearDisplay();       // Clears the display
      OLED_screen.setCursor(0, 0);      // Initializes the cursor at (0,0)
      OLED_screen.setTextSize(3);       // Increases the size of the characters
      OLED_screen.setTextColor(SSD1306_BLACK, SSD1306_WHITE); // Text color black and background color white
      // Prints "Flex Sensor" to the OLED screen
      OLED_screen.println("Flex");
      OLED_screen.println("Sensor");
    }
    else if(encoder0Pos == 2) { // encoder0Pos == 2 corresponds to the "Lowtech sensor" mode
      OLED_screen.clearDisplay();       // Clears the display
      OLED_screen.setCursor(0, 0);      // Initializes the cursor at (0,0)
      OLED_screen.setTextSize(3);       // Increases the size of the characters
      OLED_screen.setTextColor(SSD1306_BLACK, SSD1306_WHITE); // Text color black and background color white
      // Prints "Lowtech Sensor" to the OLED screen
      OLED_screen.println("Lowtech");
      OLED_screen.println("Sensor");
    }
    else if(encoder0Pos == 3) { // encoder0Pos == 3 corresponds to the "GitHub QR" mode
      OLED_screen.clearDisplay(); // Clears the display
      OLED_screen.drawBitmap(0, 0, epd_bitmap_frame, 128, 64, WHITE); // Prints a bitmap of the QR code from the homemade library QR.h
    } 
  }
  // Updates the information displayed on the OLED screen
  OLED_screen.display();
}


/////////////////////////////////////////// BLUETOOTH COMMUNICATION FUNCTIONS ///////////////////////////////////////
// switchSerialEvent is run every time data is received from the application via Bluetooth
void switchSerialEvent(){
  serialRX = switchSerial.read(); // Reads the message from the application
  RX = 1; // Switches the state of RX
}


// Function for handling the incomming data from the application via Bluetooth
void bluetooth_data_handling(){
  if (RX){ // RX is 1 if a switchSerialEvent has been triggered, indicating there is data to receive
    RX=0;  // Resets the state of RX so that the function is only called when a new message is sent from the application
    switch (serialRX) {
    case 1: // If the Arduino UNO receives the message 1, start is set to 1 and a measure starts
      Serial.println("Start button pressed!");
      start = 1;
      break;
    case 2: // If the Arduino UNO receives the message 2, start is set to 0 and the measure stops
      Serial.println("Stop button pressed!");
      start = 0;
      break;
    }
  }
}


/////////////////////////////////////////// FLEX SENSOR FUNCTIONS ///////////////////////////////////////////////////
// Function for determining the resistance of the commercial flex sensor
void flex_getResistance() {
  int ADCflex = analogRead(flexPin); // Gets the value of the flexPin in bits
  float Vflex = ADCflex * Vcc / 1023.0; // Transfers the bit value into tension
  float Rflex = R_DIV * (Vcc / Vflex - 1.0); // Transfers the tension value into resistance
  Serial.println("Resistance: " + String(Rflex) + " ohms"); // Prints the resistance to the serial monitor
  switchSerial.println(Rflex); // Transfers the resistance value to the application over Bluetooth

  // Uses the calculated resistance to estimate the sensor's bend angle:
  float angle = map(Rflex, flatResistance, bendResistance, 0, 90.0); // Calculates the angle based on the flat resistance, the resistance at 90 degrees and the current resistance
  Serial.println("Bend: " + String(angle) + " degrees"); // Prints the current angle to the serial monitor
}


/////////////////////////////////////////// DIGITAL POTENTIOMETER FUNCTIONS /////////////////////////////////////////
// Function for changing the value of the digital potentiometer
void potentiometer_setWiper(int addr, int pos) {
  pos = constrain(pos, 0, 255);            // Limits wiper setting to range of 0 to 255
  digitalWrite(csPin, LOW);                // Selects chip
  SPI.transfer(addr);                      // Configures target pot with wiper position
  SPI.transfer(pos);                       // Configures potentiometer position
  digitalWrite(csPin, HIGH);               // De-selects chip
  resistanceWB = ((rAB * potentiometerWiperPos) / maxPositions ) + rWiper; // Calculates the new potentiometer resistance
}


// Function for calibrating the potentiometer the first time "graphite mode" is entered
void calibrate_potentiometer() {
  int Vadc = 0; // Initializes Vadc
  Serial.println("Calibrating potentiometer");
  while(!calibrated) {
    potentiometer_setWiper(pot0, potentiometerWiperPos); // Sets the current wiper position
    Vadc = analogRead(graphitePin); // Checks the current value of Vadc (output signal form the graphite sensor)
    Serial.print("Vadc : ");
    Serial.println(Vadc); // Prints the current Vadc value to the serial monitor
    // If Vadc never reaches the goal value the potentiometer will continue lowering its wiper position, this if stops it at 1
    if (potentiometerWiperPos < 2) { 
      calibrated = 1;
      break;
    }
    // Sets the potentiometer value so that the graphite sensor signal ends up between 500 and 520 bits (the middle of the spectrum)
    if (Vadc < 500){
      potentiometerWiperPos--;
    }
    else if (Vadc > 520){
      potentiometerWiperPos++;
    }
    else calibrated = 1;
    // Prints the wiper position of the potentiometer to the serial monitor
    Serial.println(potentiometerWiperPos);
    delay(100); //Small delay for stability
  }
}


/////////////////////////////////////////// GRAPHITE SENSOR FUNCTIONS ///////////////////////////////////////////////
// Function for determining the resistance of the LowTech graphite sensor
void graphite_getResistance() {
  // Updates the potentiometer value
  potentiometer_setWiper(pot0, potentiometerWiperPos);

  // Calculates and transmits the resistance value of the graphite sensor
  float sensorValue = analogRead(graphitePin); // Reads the input value on pin A0 in bits
  if (!calibrated) calibrate_potentiometer();  // Calibrates the digital potentiometer the first time the program enters "graphite mode"
  else{ // Runs when in "graphite mode" after the first calibration of the potentiometer
    float Rc = (float(1024)/float(sensorValue))*r1*(1+r3/float(resistanceWB))-r1-r5; // Calculates the resistance of the graphite sensor
    Serial.print ("Resistance of graphite sensor ");
    Serial.println (Rc); // Prints the resistance to the serial monitor
    switchSerial.println(Rc); // Transfers the resistance value to the application over Bluetooth
  }   
}

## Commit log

2026-02-10 added KiCad file
    [TestKiCad.kicad_pcb, TestKiCad.kicad_sch]
2026-04-05 STL file of 3D print for flex test
    [Projet_MOSH.stl]
2026-04-06 Added KiCad files
    [Capteur_Graphite.kicad_pcb, Capteur_Graphite.kicad_sch]
2026-04-12 Added files for the current Arduino programs
2026-04-12 Clean-ups in the repositories and writing of the README.md
    [Capteur_Graphite.kicad_pcb, Capteur_Graphite.kicad_sch, Projet_MOSH.stl]
2026-04-16 Added comments and wiring descriptions to Full_code.ino
2026-04-16 Svea: added the Datasheet for the sensor as a pdf
2026-04-16 Added photos of the KiCad and LTspice
2026-04-16 Added photo of PCB 3D model
2026-04-16 Removed Test KiCad
    [TestKiCad.kicad_pcb, TestKiCad.kicad_sch]
